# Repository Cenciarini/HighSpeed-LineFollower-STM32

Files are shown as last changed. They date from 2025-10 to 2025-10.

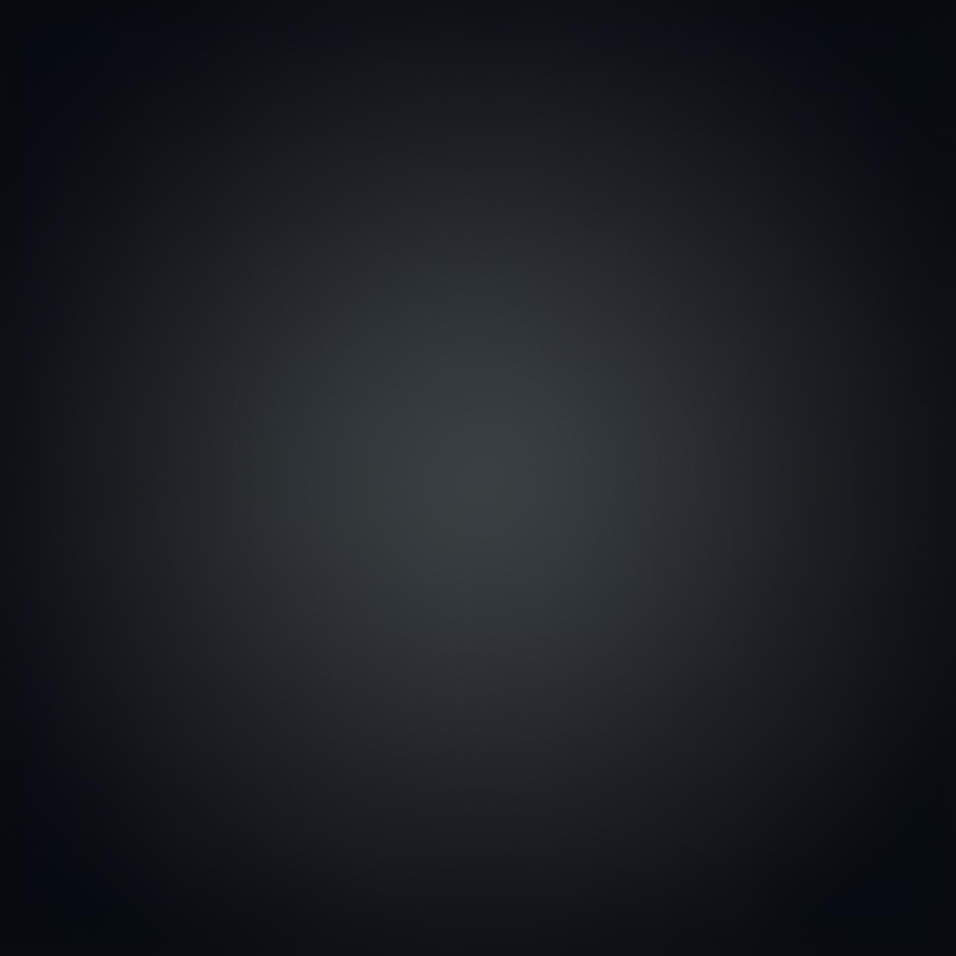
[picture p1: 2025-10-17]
QT_Micro/Imagenes/fondo.png

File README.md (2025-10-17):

# 🚀 High-Speed Line Follower Robot — STM32 Bluepill






---

## 📖 Descripción general

Este proyecto presenta el desarrollo completo de un **robot móvil seguidor de línea de alta velocidad**, basado en un **microcontrolador STM32F103C8T6 (Bluepill)**.  
El sistema fue diseñado para lograr **gran precisión y estabilidad a altas velocidades** mediante el uso de **controladores PID independientes para cada rueda** y una arquitectura modular que integra hardware, firmware, modelado 3D y una interfaz de control desde PC.

El robot combina múltiples disciplinas de ingeniería:  
- ⚙️ **Diseño electrónico y PCB**  
- 💻 **Programación embebida en C**  
- 🧠 **Control en tiempo real (PID)**  
- 🌐 **Comunicación inalámbrica vía ESP32 / UDP**  
- 🖥️ **Interfaz gráfica en C++ con Qt Creator**  
- 🧩 **Diseño mecánico en SolidWorks**

---

## 🧰 Estructura del repositorio

```
📦 RobotLineFollower_STM32
│
├── PCB_Micro/
│   ├── schematics/
│   ├── gerbers/
│   └── README.md
│   📘 Contiene el diseño electrónico completo en KiCAD.
│
├── QT_Micro/
│   ├── mainwindow.cpp
│   ├── resources/
│   └── README.md
│   💻 Interfaz de usuario en Qt Creator (C++) para control remoto y monitoreo.
│
├── SOLID_Micro/
│   ├── ensamblajes/
│   ├── piezas/
│   └── archivos_stl/
│   🧩 Modelos 3D y partes imprimibles diseñadas en SolidWorks.
│
├── ST_Micro/
│   ├── Core/
│   ├── Drivers/
│   ├── Src/
│   └── Inc/
│   ⚙️ Proyecto en STM32CubeIDE con firmware completo para el Bluepill.
│
└── README.md
```

---

## ⚙️ ST_Micro — Firmware embebido

El firmware principal está implementado en **C** dentro de `STM32CubeIDE`, con soporte para múltiples periféricos del microcontrolador.  
Entre sus módulos más relevantes se incluyen:

### 🔧 Periféricos utilizados
- **I2C:** Lectura de sensor **MPU6050** (acelerómetro + giroscopio).  
- **DMA:** Adquisición continua de señales **ADC** para los sensores IR.  
- **PWM:** Control preciso de la velocidad de cada motor DC.  
- **UART:** Comunicación con módulo **ESP01 (WiFi)** para envío de datos vía UDP.  
- **Timers:** Sincronización de tareas y control de tiempo de muestreo.  
- **ADC:** Lectura analógica de los sensores de línea.  

### 🧠 Control PID
El control PID ajusta dinámicamente las velocidades de ambas ruedas para mantener el robot centrado sobre la línea incluso en curvas pronunciadas o a altas velocidades.

El algoritmo se ejecuta en tiempo real y los parámetros **Kp, Ki, Kd** pueden modificarse desde la interfaz gráfica mediante comunicación **UDP**.

### 🧾 Librerías implementadas
- `comunicaciones.c`: Implementa un protocolo propio con chequeo de errores y estructura de tramas (`HEADER`, `NBYTES`, `PAYLOAD`, `CKS`).  
- `ESP01.c`: Gestión completa del módulo WiFi ESP01 con comandos AT y control de estados.  
- `ssd1306.c` y `fonts.c`: Control del display OLED (visualización de estados del robot).  
- `main.c`: Orquesta la lógica principal, incluyendo adquisición de datos, control PID, comunicación, y visualización en pantalla.

---

## 💻 QT_Micro — Interfaz gráfica de control

Desarrollada en **Qt Creator (C++)**, esta interfaz permite:

- Conexión con el robot a través de **UDP (ESP32 o ESP01)**.  
- Ajuste dinámico de parámetros PID (Kp, Ki, Kd) para cada rueda.  
- Visualización en tiempo real de:
  - Estado del robot y sensores IR.
  - Gráficos del recorrido.
  - Datos del MPU6050 (ángulos, aceleraciones).  
- Control remoto del robot (inicio/parada, velocidad base, direcciones, etc.).

---

## ⚡ PCB_Micro — Electrónica y PCB

Diseñada completamente en **KiCAD**, esta placa integra:

- Microcontrolador **STM32F103C8T6** (Bluepill).  
- Etapa de potencia con control PWM para motores DC.  
- Sensores IR analógicos para detección de línea.  
- Reguladores de tensión y protección de alimentación.  
- Conectores para display OLED, ESP01, MPU6050 y ST-Link.  

Incluye:
- Archivos **.sch** (esquemáticos)
- Archivos **.kicad_pcb**
- Archivos **Gerber** listos para fabricación

---

## 🧩 SOLID_Micro — Diseño mecánico

El diseño mecánico del robot fue modelado íntegramente en **SolidWorks**, con foco en minimizar peso y tamaño manteniendo la rigidez estructural.  
Se incluyen:
- Ensambles del chasis y soporte de sensores.  
- Piezas STL listas para impresión 3D.  
- Montaje optimizado del PCB y baterías.

---

## 📡 Comunicación y protocolo

El robot y la interfaz de PC se comunican mediante **UDP**, usando un **protocolo propio de mensajes binarios** desarrollado en C.  
Cada mensaje posee estructura de seguridad y verificación de checksum, garantizando robustez en entornos de alta velocidad.

---

## 🧠 Principales características técnicas

| Componente | Descripción |
|---|---|
| **Microcontrolador** | STM32F103C8T6 (Cortex-M3, 72 MHz) |
| **Sensores** | IR analógicos + MPU6050 (I2C) |
| **Pantalla** | OLED SSD1306 (I2C) |
| **Comunicación** | ESP01 (UART → UDP) / Interfaz Qt |
| **Control** | PID doble canal (rueda izquierda / derecha) |
| **Alimentación** | Batería Li-Po 7.4V con regulación interna |
| **Software principal** | STM32CubeIDE, KiCAD, Qt Creator, SolidWorks |

---

## 🧠 Habilidades demostradas

Este proyecto refleja competencias avanzadas en:

- Diseño y fabricación de **PCBs profesionales** con KiCAD.  
- Programación de **firmware embebido en C para microcontroladores STM32**.  
- Implementación de **controladores PID en tiempo real**.  
- Desarrollo de **protocolos de comunicación personalizados**.  
- Integración de **periféricos complejos (ADC, DMA, I2C, UART, PWM)**.  
- Diseño de **interfaces gráficas multiplataforma (Qt Creator)**.  
- Diseño **mecánico 3D y prototipado rápido (SolidWorks)**.  

---

## 📄 Licencia

Este proyecto está licenciado bajo los términos de la **MIT License**.  
Consulta el archivo [LICENSE](LICENSE) para más información.

---

## 👤 Autor

**Gabriel Cenciarini**  
Ingeniero Mecatrónico
📧 [LinkedIn](https://www.linkedin.com/in/cenciarinigabriel/) | 💻 [GitHub](https://github.com/Cenciarini)

---

> “La integración entre electrónica, software y control no solo construye robots, sino ingenieros capaces de pensar en sistemas completos.”

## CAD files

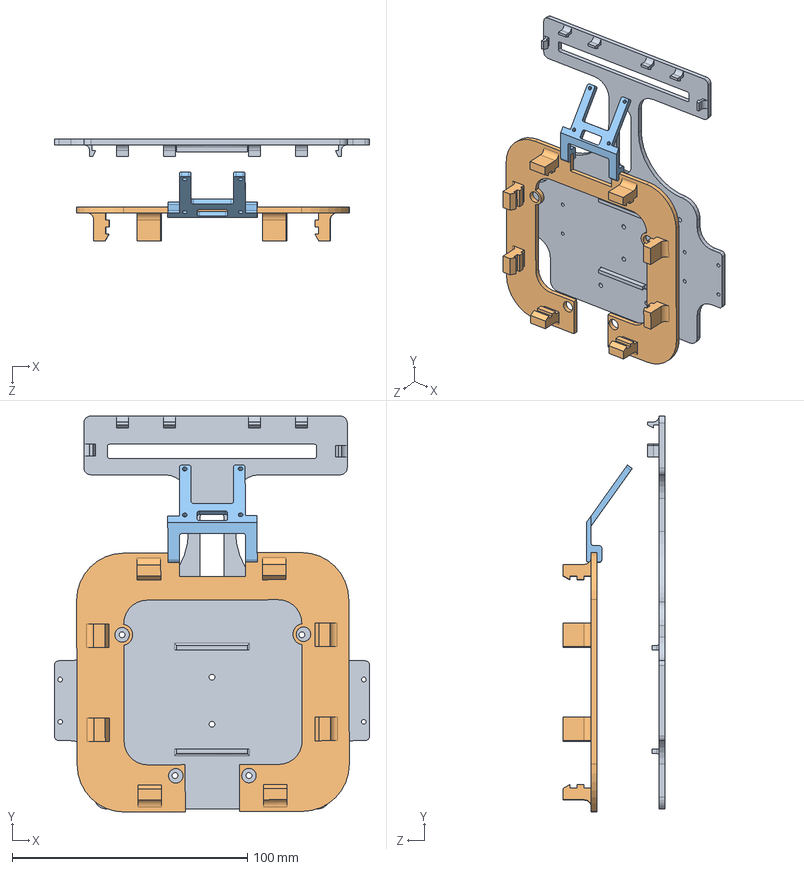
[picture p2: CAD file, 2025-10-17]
SOLID_Micro/Ensamblaje1.SLDASM
134.0 x 168.3 x 43.4 mm
Base
PiezaSuperior
Pantalla

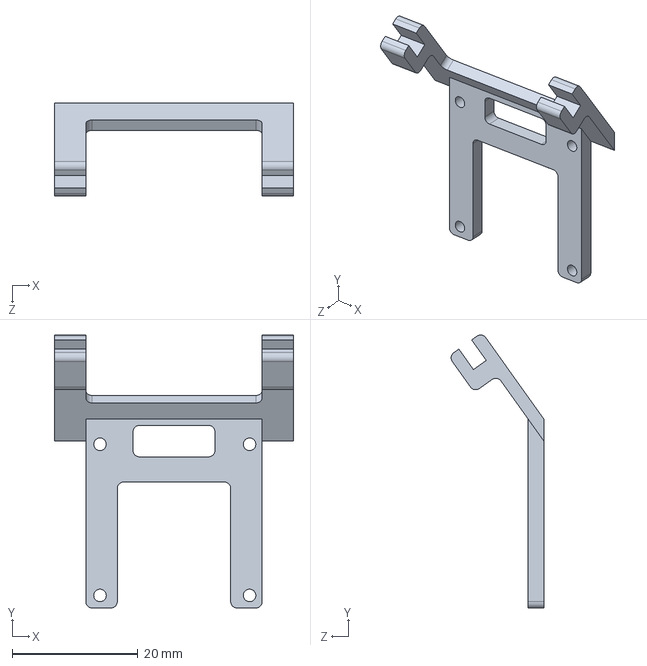
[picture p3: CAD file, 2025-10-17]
SOLID_Micro/Pantalla.SLDPRT
38.0 x 43.4 x 14.7 mm

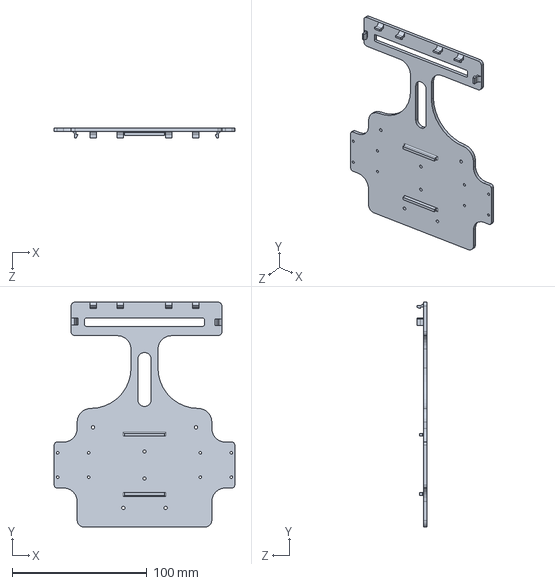
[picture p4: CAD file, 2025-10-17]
SOLID_Micro/Base.SLDPRT
134.0 x 167.0 x 7.50 mm

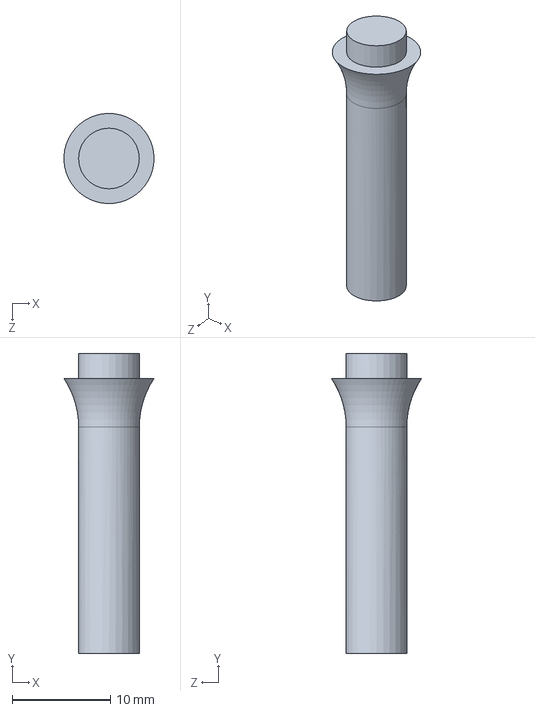
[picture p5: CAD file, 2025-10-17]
SOLID_Micro/Columna.SLDPRT
9.19 x 30.6 x 9.19 mm

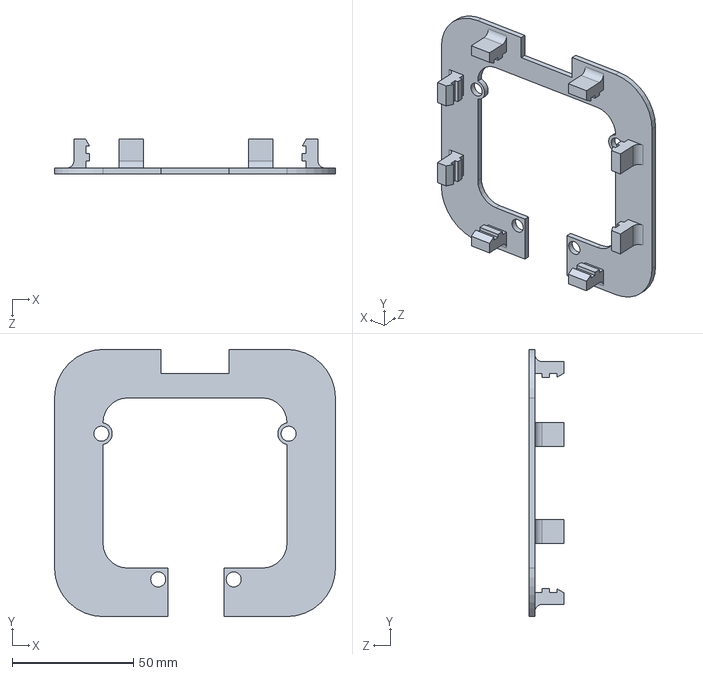
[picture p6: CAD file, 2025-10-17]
SOLID_Micro/PiezaSuperior.SLDPRT
115.7 x 110.0 x 14.5 mm

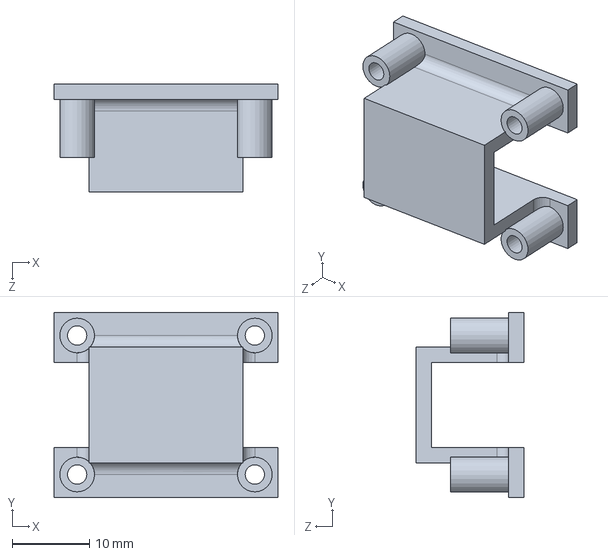
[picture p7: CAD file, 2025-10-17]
SOLID_Micro/SoporteMotor.SLDPRT
29.0 x 24.0 x 14.0 mm

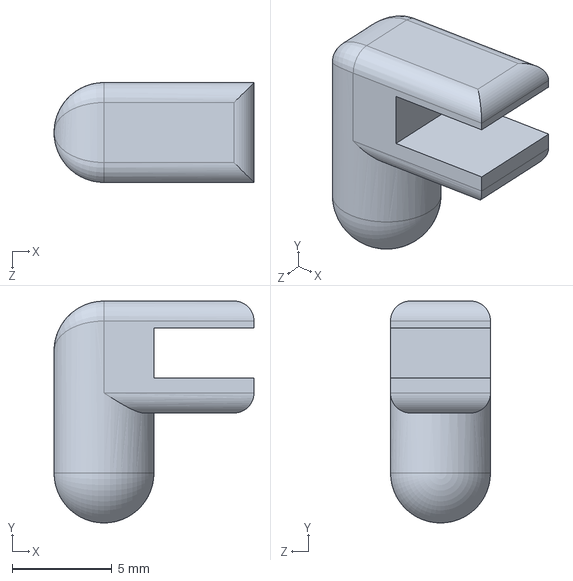
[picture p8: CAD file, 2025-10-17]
SOLID_Micro/Apoyo.SLDPRT
10.0 x 11.1 x 5.00 mm

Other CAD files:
SOLID_Micro/STLs/Apoyo.STL
SOLID_Micro/STLs/Base.STL
SOLID_Micro/STLs/Columna.STL
SOLID_Micro/STLs/Pantalla.STL
SOLID_Micro/STLs/PiezaSuperior.STL
SOLID_Micro/STLs/SoporteMotor.STL

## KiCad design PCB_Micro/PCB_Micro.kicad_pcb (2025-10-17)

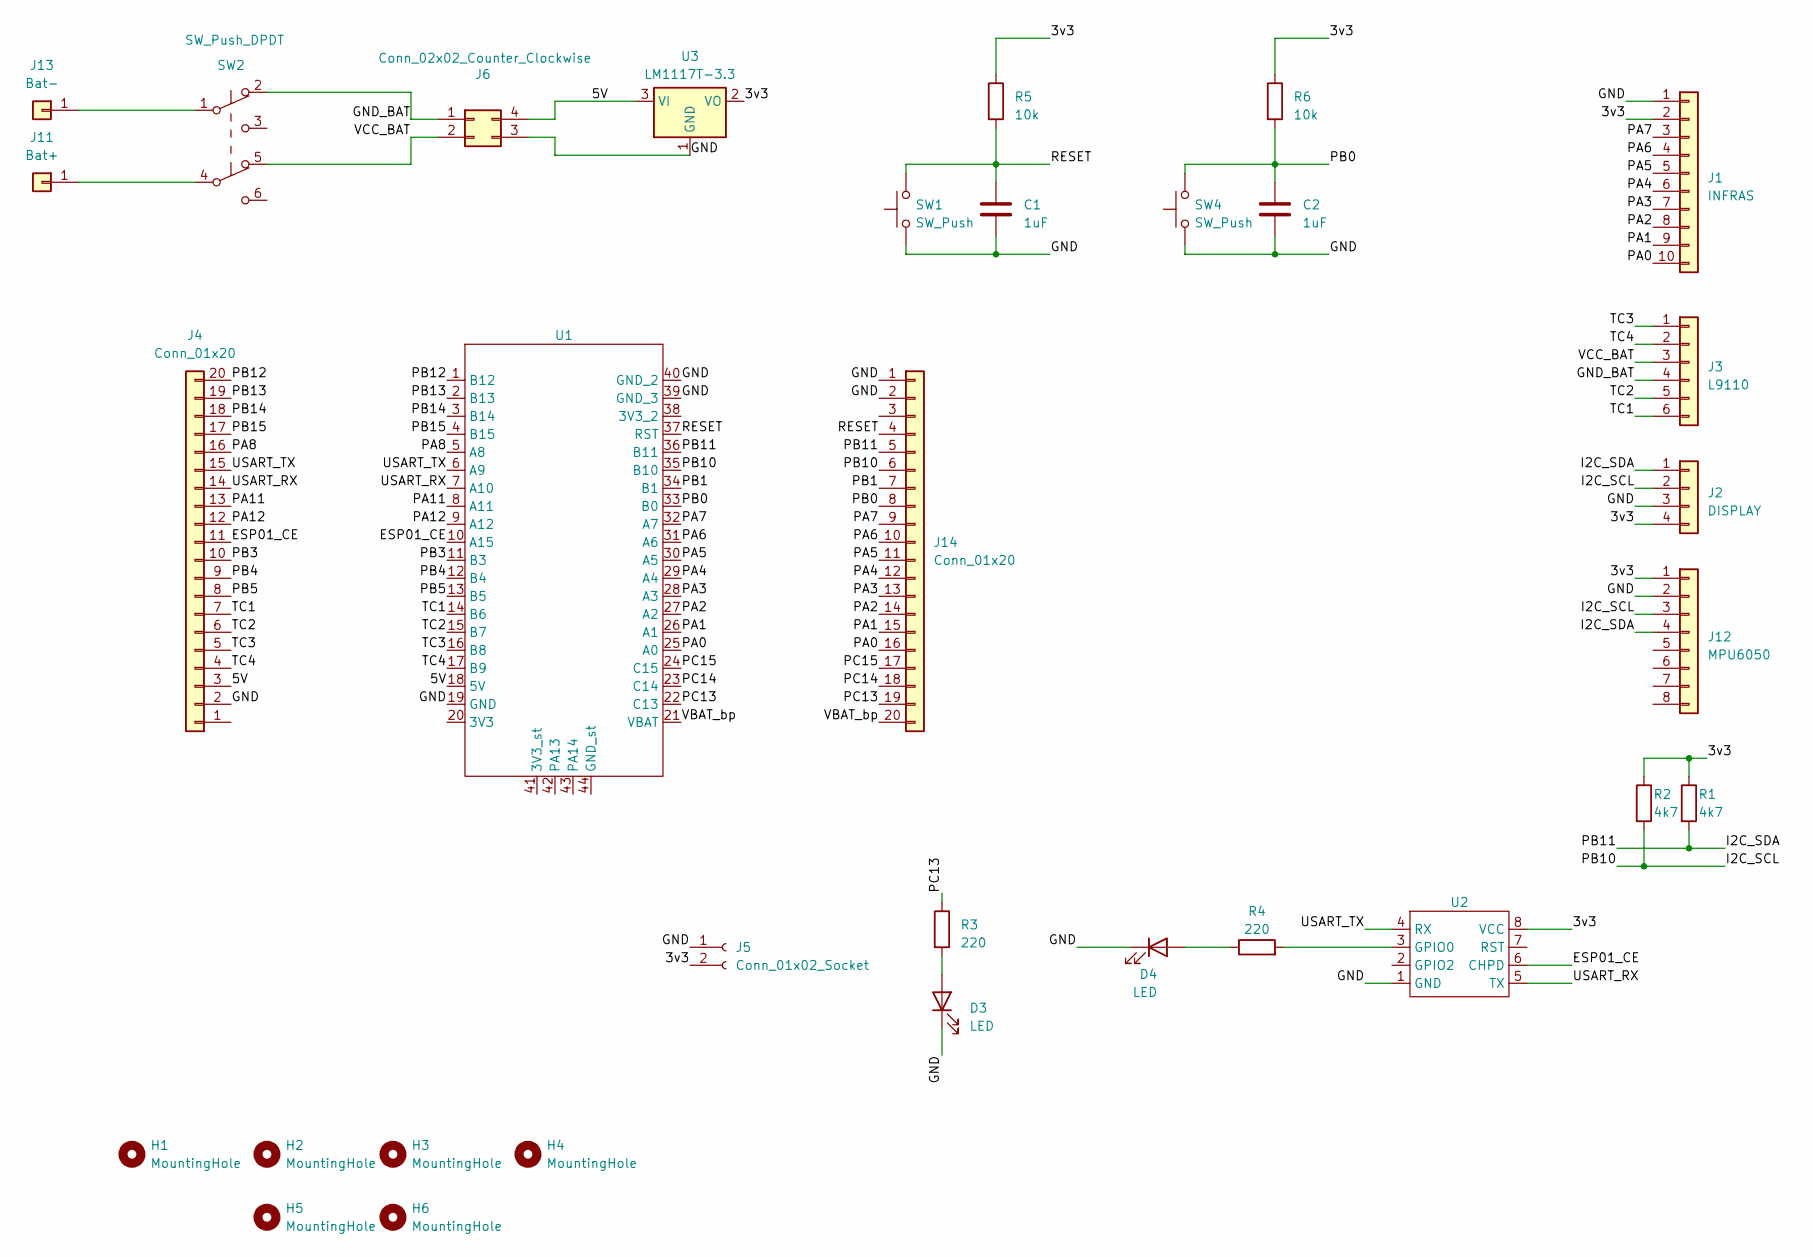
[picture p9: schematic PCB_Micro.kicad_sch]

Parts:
C1, C2: 1uF; C_Disc_D3.8mm_W2.6mm_P2.50mm
D3, D4: LED; LED_D3.0mm
H1, H2, H3, H4, H5, H6: MountingHole; MountingHole_3.2mm_M3
J1: INFRAS; PinHeader_1x10_P2.54mm_Horizontal
J2: DISPLAY; PinSocket_1x04_P2.54mm_Vertical
J3: L9110; PinSocket_1x06_P2.54mm_Vertical
J4, J14: Conn_01x20; PinSocket_1x20_P2.54mm_Vertical
J5: Conn_01x02_Socket; PinSocket_1x02_P2.54mm_Vertical
J6: Conn_02x02_Counter_Clockwise; MINI360Module
J11: Bat+; PinSocket_1x01_P2.54mm_Vertical
J12: MPU6050; PinSocket_1x08_P2.54mm_Vertical
J13: Bat-; PinSocket_1x01_P2.54mm_Vertical
R1, R2: 4k7; R_Axial_DIN0207_L6.3mm_D2.5mm_P10.16mm_Horizontal
R3, R4: 220; R_Axial_DIN0207_L6.3mm_D2.5mm_P10.16mm_Horizontal
R5, R6: 10k; R_Axial_DIN0207_L6.3mm_D2.5mm_P10.16mm_Horizontal
SW1, SW4: SW_Push; SW_PUSH_6mm_H4.3mm
SW2: SW_Push_DPDT; SW_Push_2P2T_Toggle_CK_PVA2xxH1xxxxxxV2
U1: STM32BluePill
U2: XCVR_ESP8266-01_ESP-01
U3: LM1117T-3.3; TO-220-3_Vertical

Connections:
/3v3: J1.2, J2.4, J5.2, J12.1, R1.1, R2.1, R5.1, R6.1, U2.8 (VCC), U3.2 (VO)
/5V: J4.3, J6.4, U1.18 (5V), U3.3 (VI)
/ESP01_CE: J4.11, U1.10 (A15), U2.6 (CHPD)
/GND: C1.2, C2.2, D3.1 (K), D4.1 (K), J1.1, J2.3, J4.2, J5.1, J6.3, J12.2, J14.1, J14.2, SW1.1, SW4.1, U1.19 (GND), U1.39 (GND_3), U1.40 (GND_2), U2.1 (GND), U3.1 (GND)
/GND_BAT: J3.4, J6.1, SW2.2 (A)
/I2C_SCL: J2.2, J12.3, J14.6, R2.2, U1.35 (B10)
/I2C_SDA: J2.1, J12.4, J14.5, R1.2, U1.36 (B11)
/PA0: J1.10, J14.16, U1.25 (A0)
/PA1: J1.9, J14.15, U1.26 (A1)
/PA2: J1.8, J14.14, U1.27 (A2)
/PA3: J1.7, J14.13, U1.28 (A3)
/PA4: J1.6, J14.12, U1.29 (A4)
/PA5: J1.5, J14.11, U1.30 (A5)
/PA6: J1.4, J14.10, U1.31 (A6)
/PA7: J1.3, J14.9, U1.32 (A7)
/PA8: J4.16, U1.5 (A8)
/PA11: J4.13, U1.8 (A11)
/PA12: J4.12, U1.9 (A12)
/PB0: C2.1, J14.8, R6.2, SW4.2, U1.33 (B0)
/PB1: J14.7, U1.34 (B1)
/PB3: J4.10, U1.11 (B3)
/PB4: J4.9, U1.12 (B4)
/PB5: J4.8, U1.13 (B5)
/PB12: J4.20, U1.1 (B12)
/PB13: J4.19, U1.2 (B13)
/PB14: J4.18, U1.3 (B14)
/PB15: J4.17, U1.4 (B15)
/PC13: J14.19, R3.1, U1.22 (C13)
/PC14: J14.18, U1.23 (C14)
/PC15: J14.17, U1.24 (C15)
/RESET: C1.1, J14.4, R5.2, SW1.2, U1.37 (RST)
/TC1: J3.6, J4.7, U1.14 (B6)
/TC2: J3.5, J4.6, U1.15 (B7)
/TC3: J3.1, J4.5, U1.16 (B8)
/TC4: J3.2, J4.4, U1.17 (B9)
/USART_RX: J4.14, U1.7 (A10), U2.5 (TX)
/USART_TX: J4.15, U1.6 (A9), U2.4 (RX)
/VBAT_bp: J14.20, U1.21 (VBAT)
/VCC_BAT: J3.3, J6.2, SW2.5 (A)
unnamed: D3.2 (A), R3.2
unnamed: D4.2 (A), R4.1
unnamed: J11.1, SW2.4 (B)
unnamed: J13.1, SW2.1 (B)
unnamed: R4.2, U2.3 (GPIO0)

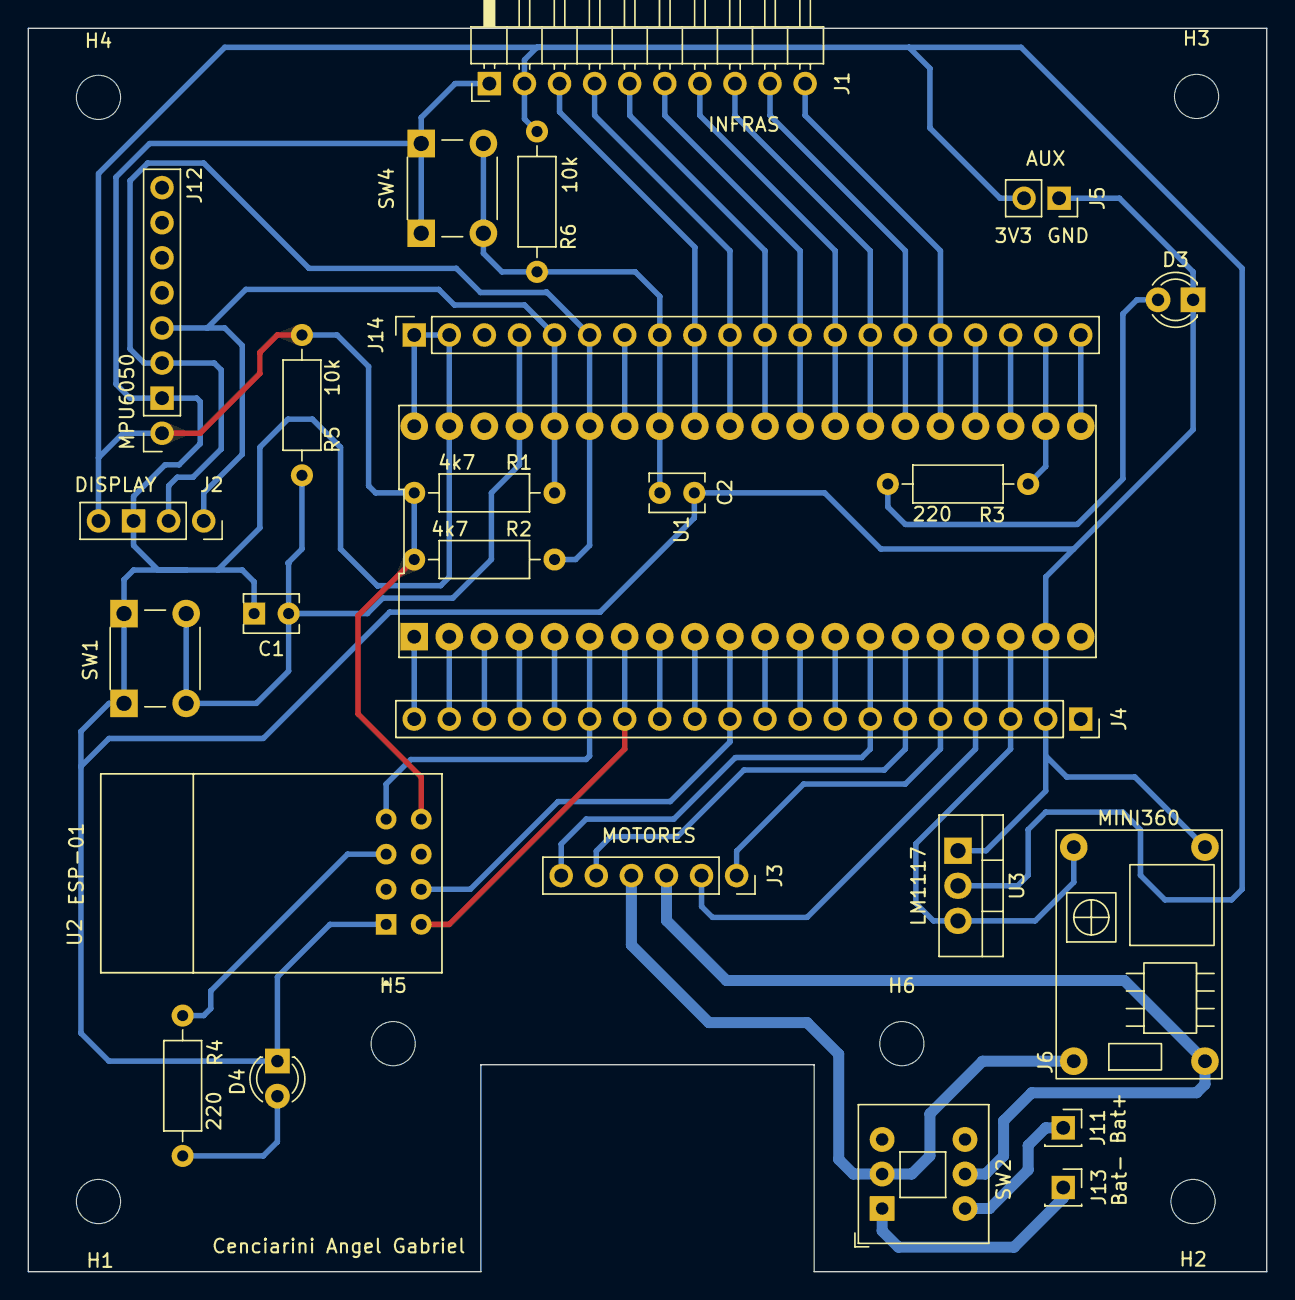
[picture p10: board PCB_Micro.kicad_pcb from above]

Board: 2 copper layers, 89.7 x 90.0 mm, 32 parts (0 on the bottom side), 44 nets.

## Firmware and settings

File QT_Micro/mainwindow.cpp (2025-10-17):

#include "mainwindow.h"
#include "ui_mainwindow.h"
#include <QtNetwork/QUdpSocket>
#include <QElapsedTimer>
#include <QPixmap>
#include <qdebug.h>

#define PI 3.14159162
#define H 54.0
#define Alpha 0.97738

MainWindow::MainWindow(QWidget *parent)
    : QMainWindow(parent)
    , ui(new Ui::MainWindow)
{
    ui->setupUi(this);

    // Initialize the track visualization widget
    Qpista1 = new qpista(1348,561,ui->QPista);

    // Initialize UDP sockets for communication
    mSocket_send = new QUdpSocket(this);
    mSocket_recive = new QUdpSocket(this);

    // Bind receiving socket to local IP and port for listening
    mSocket_recive->bind(QHostAddress("192.168.2.114"), 30001, QUdpSocket::ShareAddress);

    // Connect signal for incoming data to read handler
    connect(mSocket_recive, &QUdpSocket::readyRead, this, &MainWindow::readDatagrams);
}

MainWindow::~MainWindow()
{
    // Clean up dynamically allocated memory
    delete Qpista1;
    delete ui;
}

//-------------------------------------------------------------------------------------------------
// Resize event handler: updates the track widget size and UI labels when the main window resizes.
//-------------------------------------------------------------------------------------------------
void MainWindow::resizeEvent(QResizeEvent */*event*/)
{
    Qpista1->resize(ui->QPista->size());
    ui->label_5->setText(QString().number(ui->QPista->width()));
    ui->label_6->setText(QString().number(ui->QPista->height()));
}

//-------------------------------------------------------------------------------------------------
// Paint event: ensures the track is resized only once during initial rendering.
//-------------------------------------------------------------------------------------------------
void MainWindow::paintEvent(QPaintEvent */*event*/)
{
    static bool first = false;

    if(!first){
        Qpista1->resize(ui->QPista->size());
        first = true;
    }
}

//-------------------------------------------------------------------------------------------------
// Sends the currently selected datagram command over UDP when the push button is clicked.
//-------------------------------------------------------------------------------------------------
void MainWindow::on_pushButton_clicked()
{
    datagramaWrite.resize(seleccion.size());
    datagramaWrite = seleccion;

    if(commandSend == 172){
        firstRead = 1;
    }
    if(commandSend == 171){
        raceStart = !raceStart;
    }

    qDebug() << commandSend;

    // Transmit datagram to target device (local or lab)
    mSocket_send->writeDatagram(datagramaWrite, QHostAddress("192.168.2.115"), 30010);  // Home
    //mSocket_send->writeDatagram(datagramaWrite, QHostAddress("192.168.2.108"), 30001); // Lab prototype
}

//-------------------------------------------------------------------------------------------------
// Updates the datagram structure according to the selected command in the combo box.
//-------------------------------------------------------------------------------------------------
void MainWindow::on_comboBox_currentIndexChanged(int index)
{
    seleccion.resize(9);

    switch (index) {
    case 0:
        break;
    case 1:
        // ALIVE command
        seleccion[0] = 'U';
        seleccion[1] = 'N';
        seleccion[2] = 'E';
        seleccion[3] = 'R';
        seleccion[4] = 0x02;
        seleccion[5] = 0x3A;
        seleccion[6] = 0xF0;
        seleccion[7] = 0xC4;
        seleccion[8] = '\0';
        break;
    case 2:
        // Accelerometer/Gyroscope data request
        seleccion[0] = 'U';
        seleccion[1] = 'N';
        seleccion[2] = 'E';
        seleccion[3] = 'R';
        seleccion[4] = 0x02;
        seleccion[5] = 0x3A;
        seleccion[6] = 0xAC;
        seleccion[7] = 0x98;
        seleccion[8] = '\0';
        break;
    case 3:
        // Command for another operation
        seleccion[0] = 'U';
        seleccion[1] = 'N';
        seleccion[2] = 'E';
        seleccion[3] = 'R';
        seleccion[4] = 0x02;
        seleccion[5] = 0x3A;
        seleccion[6] = 0xAB;
        seleccion[7] = 0x9F;
        seleccion[8] = '\0';
        break;
    case 4:
        // Alternative system command
        seleccion[0] = 'U';
        seleccion[1] = 'N';
        seleccion[2] = 'E';
        seleccion[3] = 'R';
        seleccion[4] = 0x02;
        seleccion[5] = 0x3A;
        seleccion[6] = 0xA5;
        seleccion[7] = 0x91;
        seleccion[8] = '\0';
        break;
    default:
        break;
    }

    commandSend = seleccion[6];
}

//-------------------------------------------------------------------------------------------------
// Reads available UDP datagrams and triggers the decoding routine.
//-------------------------------------------------------------------------------------------------
void MainWindow::readDatagrams()
{
    if(mSocket_recive->hasPendingDatagrams()) {
        datagramaRead.resize(int(mSocket_recive->pendingDatagramSize()));
        mSocket_recive->readDatagram(datagramaRead.data(),datagramaRead.size());
    }
    decodeDatagram();
}

//-------------------------------------------------------------------------------------------------
// Decodes incoming datagrams using a finite state machine to verify header, payload, and checksum.
//-------------------------------------------------------------------------------------------------
void MainWindow::decodeDatagram()
{
    uint8_t index = 0, indexPayload = 0;

    while (index != datagramaRead.size()) {
        switch (stateDecode)
        {
        case 0:
            // Expect header byte 'U'
            if (datagramaRead[index++] == 'U') {
                stateDecode = 1;
                cksRx = 0;
            }else{
                stateDecode = 0;
                command = ERROR;
                return;
            }
            break;
        case 1:
            // Expect 'N'
            if (datagramaRead[index++] == 'N') {
                stateDecode = 2;
            }else{
                stateDecode = 0;
                command = ERROR;
                return;
            }
            break;
        case 2:
            // Expect 'E'
            if (datagramaRead[index++] == 'E'){
                stateDecode = 3;
            }else{
                stateDecode = 0;
                command = ERROR;
                return;
            }
            break;
        case 3:
            // Expect 'R'
            if (datagramaRead[index++] == 'R'){
                stateDecode = 4;
            }else{
                stateDecode = 0;
                command = ERROR;
                return;
            }
            break;
        case 4:
            // Payload size
            nBytes = datagramaRead[index++];
            stateDecode = 5;
            break;
        case 5:
            // Expect ':' separator and compute checksum seed
            if (datagramaRead[index++] == ':'){
                stateDecode = 6;
                cksRx = 'U' ^ 'N' ^ 'E' ^ 'R' ^ nBytes ^ ':';
                indexPayload = 0;
            }else{
                stateDecode = 0;
                command = ERROR;
                return;
            }
            break;
        case 6:
            // Read payload and update checksum
            if(nBytes > 1){
                buff[indexPayload++] = datagramaRead[index];
                cksRx ^= datagramaRead[index++];
            }
            nBytes--;
            // Validate checksum once payload is complete
            if(nBytes == 0){
                stateDecode = 0;
                uint8_t cksRxAux = datagramaRead[index];
                if(cksRx == cksRxAux){
                    analisisData();
                }
            }
            break;
        default:
            break;
        }
    }
}

//-------------------------------------------------------------------------------------------------
// Processes valid decoded data depending on the command type and updates the GUI accordingly.
//-------------------------------------------------------------------------------------------------
void MainWindow::analisisData()
{
    switch (buff[0]) {
    case 0xF0:
        ui->label_7->setText("Estoy vivo");
        break;

    case 0xAC:  {
        // Parse IMU data (accelerometer and gyroscope)
        accelX = (buff[1] << 8) | buff[2];
        accelY = (buff[3] << 8) | buff[4];
        gyroZ = (buff[5] << 8) | buff[6];

        // Initialize variables
        gZ = 0.0;
        aX = 0.0;
        aY = 0.0;
        theta = 0.0;

        // Convert raw data to physical units
        gZ = ((float)gyroZ / 131.0);
        aX = ((float)accelX / 16384.0) * 9810.0;
        aY = ((float)accelY / 16384.0) * 9810.0;

        aX *= 2;
        aY *= 2;

        // Offset calibration at first reading
        if(firstRead == 1){
            timer.start();
            aYOffset = aY;
            aXOffset = aX;
            gZOffset = gZ;
            firstRead = 0;
        }else{
            // Apply offset compensation
            aX -= aXOffset;
            aY -= aYOffset;
            gZ -= gZOffset;

            // Deadband filtering for noise reduction
            if(aY > -50.0 && aY < 50.0) aY = 0.0;
            if(aX > -50.0 && aX < 50.0) aX = 0.0;

            dT = timer.elapsed() / 1000.0;
            timer.restart();

            // Integrate angular rate to compute orientation
            if(gZ > -1.0 && gZ < 1.0){
                gZ = 0.0;
            }else{
                gZ = (gZ * dT)/ 3.1415916;
                gT += gZ;
            }

            // Keep orientation within 0–2π range
            if(gT > (2*PI)) gT -= (2 * PI);
            if(gT < 0.0) gT = (2 * PI) - gT;

            QString qvalor;
            ui->label->setText(qvalor.number(aX));
            ui->label_2->setText(qvalor.number(aY));
            ui->label_3->setText(qvalor.number(gZ));

            // Compute displacement based on acceleration and time
            aT = sqrt((aX * aX) + (aY * aY));
            sT = 0.5 * aT * dT * dT;

            sXo = sT * sin(gT);
            sYo = sT * cos(gT);

            sXf += sXo;
            sYf += sYo;

            ui->label_5->setText(qvalor.number(gT));
            ui->label_6->setText(qvalor.number(gyroDerCount));

            // Draw circuit path if enabled and race started
            if(circuitDraw == 1 && raceStart == 1){
                updateCircuitDraw();
            }
        }
        break;
    }

    case 0xAA:  {
        // Debug or status message
        char valor = buff[1];
        int ivalor = (int)valor;
        QString qvalor;
        ui->label_7->setText(qvalor.number(ivalor));
        break;
    }

    case 0xA7: {
        // Parse ADC and PWM data for IR sensors or motors
        adc_value = buff[1];
        pwmIzq = (buff[2] << 8) | buff[3];
        pwmDer = (buff[4] << 8) | buff[5];
        rateError = (int)(buff[6] << 8) | buff[7];
        QString qvalor;
        ui->label_5->setText(qvalor.number(pwmIzq));
        ui->label_6->setText(qvalor.number(pwmDer));
        ui->label_7->setText(qvalor.number(rateError));
        updateADCread();
    }
    default:
        break;
    }
}

//-------------------------------------------------------------------------------------------------
// Visualizes ADC sensor data as a graphical bar indicator on the track canvas.
//-------------------------------------------------------------------------------------------------
void MainWindow::updateADCread()
{
    QPen pen;
    QPainter paint(Qpista1->getCanvas());
    QPoint point, point_adc;
    QPoint puntoIzq, puntoDer;

    puntoIzq.setX(404);
    puntoIzq.setY(200);
    puntoDer.setX(944);
    puntoDer.setY(200);

    Qpista1->getCanvas()->fill(Qt::white);
    pen.setWidth(3);
    pen.setColor(Qt::darkBlue);
    paint.setPen(pen);
    paint.drawLine(puntoIzq,puntoDer);

    adc_value += 36;
    adc_value = adc_value/4;

    point.setX(944 - adc_value * 30);
    point.setY(170);
    point_adc.setX(944 - adc_value * 30);
    point_adc.setY(230);

    pen.setWidth(20);
    pen.setColor(Qt::darkGray);
    paint.setPen(pen);
    paint.drawLine(point,point_adc);

    Qpista1->update();
}

//-------------------------------------------------------------------------------------------------
// Draws the current trajectory of the system on the virtual track canvas.
//-------------------------------------------------------------------------------------------------
void MainWindow::updateCircuitDraw()
{
    QPen pen;
    QPainter paint(Qpista1->getCanvas());

    if(firstUpdate == 1){
        pointAnt.setX(700);
        pointAnt.setY(300);
        firstUpdate = 0;
    }

    pActX = sXf + 700;
    pActY = sYf + 300;

    pointAct.setX(pActX);
    pointAct.setY(pActY);

    pAntX = pActX;
    pAntY = pActY;

    pen.setWidth(2);
    pen.setColor(Qt::darkBlue);
    paint.setPen(pen);
    paint.drawLine(pointAnt,pointAct);
    Qpista1->update();

    pointAnt.setX(pAntX);
    pointAnt.setY(pActY);
}

//-------------------------------------------------------------------------------------------------
// Sends PID configuration parameters to the remote system via UDP.
//-------------------------------------------------------------------------------------------------
void MainWindow::on_pushButton_2_clicked()
{
    PIDdatagram.resize(16);

    PIDdatagram[0] = 'U';
    PIDdatagram[1] = 'N';
    PIDdatagram[2] = 'E';
    PIDdatagram[3] = 'R';
    PIDdatagram[4] = 0x09;
    PIDdatagram[5] = 0x3A;
    PIDdatagram[6] = 0xA6;
    PIDdatagram[7] = (char)ui->KpIzq->value();
    PIDdatagram[8] = (char)(ui->KdIzq->value() >> 8);
    PIDdatagram[9] = (char)ui->KdIzq->value();
    PIDdatagram[10] = (char)ui->KpDer->value();
    PIDdatagram[11] = (char)(ui->KdDer->value() >> 8);
    PIDdatagram[12] = (char)ui->KdDer->value();
    PIDdatagram[13] = (char)ui->VelPorc->value();

    // Compute XOR-based checksum for datagram integrity
    PIDdatagram[14] = 'U' ^ 'N' ^ 'E' ^ 'R' ^ 0x09 ^ ':' ^ 0xA6 ^ PIDdatagram[7] ^ PIDdatagram[8]  ^ PIDdatagram[9] ^ PIDdatagram[10] ^ PIDdatagram[11] ^ PIDdatagram[12] ^ PIDdatagram[13];
    PIDdatagram[15] = '\0';

    datagramaWrite.resize(PIDdatagram.size());
    datagramaWrite = PIDdatagram;

    //mSocket_send->writeDatagram(datagramaWrite, QHostAddress("192.168.2.108"), 30001); // Lab prototype
    mSocket_send->writeDatagram(datagramaWrite, QHostAddress("192.168.2.115"), 30010);  // Home
}

//-------------------------------------------------------------------------------------------------
// Handles IR sensor visualization toggle and sends corresponding command to the remote system.
//-------------------------------------------------------------------------------------------------
void MainWindow::on_checkBox_stateChanged(int arg1)
{
    QPen pen;
    QPainter paint(Qpista1->getCanvas());
    QPoint puntoIzq, puntoDer;

    puntoIzq.setX(404);
    puntoIzq.setY(200);
    puntoDer.setX(944);
    puntoDer.setY(200);

    if(arg1){
        Qpista1->getCanvas()->fill(Qt::white);
        pen.setWidth(3);
        pen.setColor(Qt::darkBlue);
        paint.setPen(pen);
        paint.drawLine(puntoIzq,puntoDer);
    }else{
        Qpista1->getCanvas()->fill(Qt::white);
    }
    Qpista1->update();

    // Build and send IR command datagram
    IRdatagram.resize(9);
    IRdatagram[0] = 'U';
    IRdatagram[1] = 'N';
    IRdatagram[2] = 'E';
    IRdatagram[3] = 'R';
    IRdatagram[4] = 0x02;
    IRdatagram[5] = 0x3A;
    IRdatagram[6] = 0xA7;
    IRdatagram[7] = 'U' ^ 'N' ^ 'E' ^ 'R' ^ 0x02 ^ ':' ^ 0xA7;
    IRdatagram[8] = '\0';

    datagramaWrite.resize(IRdatagram.size());
    datagramaWrite = IRdatagram;

    //mSocket_send->writeDatagram(datagramaWrite, QHostAddress("192.168.2.108"), 30001); // Lab prototype
    mSocket_send->writeDatagram(datagramaWrite, QHostAddress("192.168.2.115"), 30010);  // Home
}

//-------------------------------------------------------------------------------------------------
// Handles circuit drawing checkbox: toggles visualization of trajectory plotting.
//-------------------------------------------------------------------------------------------------
void MainWindow::on_checkBox_2_stateChanged(int arg1)
{
    if(arg1){
        Qpista1->getCanvas()->fill(Qt::white);
        circuitDraw = 1;
        firstUpdate = 1;
    }else{
        Qpista1->getCanvas()->fill(Qt::white);
        circuitDraw = 0;
    }
    Qpista1->update();
}

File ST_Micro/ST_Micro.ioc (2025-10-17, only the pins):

Mcu.UserName=STM32F103C8Tx
PA0-WKUP.Signal=ADCx_IN0
PA1.Signal=ADCx_IN1
PA10.Signal=USART1_RX
PA11.Signal=USB_DM
PA12.Signal=USB_DP
PA13.Signal=SYS_JTMS-SWDIO
PA14.Signal=SYS_JTCK-SWCLK
PA2.Signal=ADCx_IN2
PA3.Signal=ADCx_IN3
PA4.Signal=ADCx_IN4
PA5.Signal=ADCx_IN5
PA6.Signal=ADCx_IN6
PA8.GPIO_Label=ChipEnable
PA8.Signal=GPIO_Output
PA9.Signal=USART1_TX
PB10.Signal=I2C2_SCL
PB11.Signal=I2C2_SDA
PB6.Signal=S_TIM4_CH1
PB7.Signal=S_TIM4_CH2
PB8.Signal=S_TIM4_CH3
PB9.Signal=S_TIM4_CH4
PC13-TAMPER-RTC.GPIO_Label=LED[BUILTIN]
PC13-TAMPER-RTC.Signal=GPIO_Output
PC14-OSC32_IN.Signal=RCC_OSC32_IN
PC15-OSC32_OUT.Signal=RCC_OSC32_OUT
PD0-OSC_IN.Signal=RCC_OSC_IN
PD1-OSC_OUT.Signal=RCC_OSC_OUT

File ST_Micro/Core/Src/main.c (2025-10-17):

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
/* Includes ------------------------------------------------------------------*/
#include "main.h"
#include "usb_device.h"

/* USER CODE BEGIN Includes */
#include <string.h>
#include <stddef.h>
#include "stdint.h"
#include "usbd_cdc_if.h"
#include "comunicaciones.h"
#include "ESP01.h"
#include "stm32f1xx_hal.h"
#include "ssd1306.h"
#include "fonts.h"
/* USER CODE END Includes */

/* USER CODE BEGIN PTD */

typedef enum{
	ALIVE=0xF0,      // Identificador para mensaje de "vivo"
	DATA=0xF1,       // Identificador para transmisión de datos
	DEBUGGER=0xE3,   // Identificador para mensajes de depuración
	AT_TRANSMIT=0xA0,// Identificador para transmisión AT
	AT_CONFIG=0xA1,  // Identificador para configuración AT
	MPU_READ = 0xAC, // Identificador para lectura del sensor MPU
	IR_READ = 0xAB,  // Identificador para lectura de sensores IR
	MOTOR = 0XA5,    // Identificador para control de motores
	PID_CONFIG = 0xA6,// Identificador para configuración PID
	ADC_VALUES = 0XA7,// Identificador para graficar valores ADC
	OTHERS           // Identificador para otros comandos
}_eID;

// Definición de una unión para almacenar banderas de estado
static union{
	struct{
		uint8_t tranparentDebug: 1; // Bandera para modo de depuración transparente
		uint8_t at_transmit: 1;     // Bandera para transmisión AT
		uint8_t comillas: 1;        // Bandera para manejo de comillas en configuración AT
		uint8_t mpu_read: 1;        // Bandera para indicar lectura del sensor MPU
		uint8_t mpu_read_ok: 1;     // Bandera para indicar que la lectura del MPU fue exitosa
		uint8_t ir_read: 1;         // Bandera para indicar lectura de sensores IR
		uint8_t adc_dma_start: 1;   // Bandera para indicar inicio de DMA en ADC
		uint8_t motor_prueba: 1;    // Bandera para prueba de motores
	}bit;
	uint8_t byte;  // Variable de 8 bits para acceder a todas las banderas como un solo byte
}flags;

typedef struct{
	uint8_t bufferRx[256];
	uint8_t bufferTx[256];
	uint8_t bufferPx[256];
	uint8_t Rxir;
	uint8_t Rxiw;
	uint8_t Txir;
	uint8_t Txiw;
	uint8_t Pxir;
	uint8_t Pxiw;
}bufferST;

// Variables para configuración y almacenamiento de datos

SSD1306_COLOR_t color; // Color de la pantalla OLED
//_sESP01_CONFIG myESP01_Config; // Configuración del módulo ESP01
_eESP01STATUS currentESP01states;
bufferST bufferESP01;

/* USER CODE END PTD */

/* USER CODE BEGIN PD */
#define MPU6050_ADDRESS 0xD0 // Dirección I2C del sensor MPU6050
/* USER CODE END PD */

ADC_HandleTypeDef hadc1;
DMA_HandleTypeDef hdma_adc1;

I2C_HandleTypeDef hi2c2;

TIM_HandleTypeDef htim2;
TIM_HandleTypeDef htim3;
TIM_HandleTypeDef htim4;

UART_HandleTypeDef huart1;

/* USER CODE BEGIN PV */

// Variables de uso general
uint8_t tempRxUART[2];
//char dataRXESP01; // Variable para almacenar datos recibidos por UART
uint32_t elapsedHeartBeat = 0, elapsedESP01Receive = 0, elapsedMPU = 0, elapsedMPU_tx = 0, elapseIR = 0, elapsedADC_draw = 0;
uint32_t elapsedESP01TimeOut = 0;
int16_t pwmIzq = 0, pwmDer = 0, pwmIzqInv = 0, pwmDerInv = 0, pwmBase = 999; // Variables de control de PWM
int error = 0, lastError = 0;
int cumError = 0, rateError = 0, correccionDer = 0, correccionIzq = 0; // Variables para control PID
uint8_t KpIzq = 0, KpDer = 0,  Vel = 100; // Coeficientes PID
uint16_t KdIzq = 0, KdDer = 0;
uint8_t raceStart = 0, adcDraw = 0; // Banderas de control

// Buffers para almacenamiento y transmisión de datos
char bufPayloadRx[32]; // Buffer para recepción de datos USB
char bufPayloadTx[32]; // Buffer para transmisión de datos USB
char payloadBck[256];  // Buffer de respaldo para datos USB
char bufDebug[32];      // Buffer para mensajes de depuración
char ipBuf[16];           // Almacenamiento de la dirección IP del ESP01
char *ip;
uint8_t TxLen = 0;

// Variables para lectura del sensor MPU6050
uint8_t MPU_rx[4], accelCount = 0;
int16_t accelXProm = 0, accelYProm = 0, gyroZProm = 0, gyroYProm = 0, gyroZAux[20], gyroYAux[20], accelXAux[20], accelYAux[20];

// Variables para manejo de ADC con DMA
uint32_t adc_dma_value[7], dma_result[7][20], ir_prom_value[7]; // Almacenamiento de valores ADC
uint8_t adc_dma_count = 0;
int8_t line_pos;

// Variables para la detección de la linea
uint8_t max_value_ir = 0;  // Índice del sensor IR con el valor máximo
uint8_t last_ir = 0;
uint32_t max_value = 0;    // Valor máximo encontrado en ir_prom_value

/* USER CODE END PV */

void SystemClock_Config(void);
static void MX_GPIO_Init(void);
static void MX_DMA_Init(void);
static void MX_ADC1_Init(void);
static void MX_I2C2_Init(void);
static void MX_TIM2_Init(void);
static void MX_TIM4_Init(void);
static void MX_USART1_UART_Init(void);
static void MX_TIM3_Init(void);
/* USER CODE BEGIN PFP */
//void mypinSet();
uint8_t myI2CInit();
void myI2CWriteMulti(uint8_t address, uint8_t reg, uint8_t *data, uint16_t count);
void myI2CWrite(uint8_t address, uint8_t reg, uint8_t data);
void decode(uint8_t *payloadBuf, uint8_t lenPx);
void onUSBRx(char *myBuf, int length);
//uint8_t onWiFiTx(char Txdata);
//void onWiFiRx(char *Rxdata, int RxLength);
//void TxCOM(uint8_t *TxBuf, int length);
void display_debug(char txt[],uint8_t X,uint8_t Y);
void MPU6050_Read_Data(void);
uint8_t MPU6050_Init(void);
void IR_PROMEDIO();
void MPU_PROMEDIO();
int8_t Line_detection();
void Pwm_Step();

void ESP01_CH_PD_Set(uint8_t value);
void ESP01_UART_Receive(uint8_t value);
int ESP01_UART_Send(uint8_t value);
void ESP01_ChangeState(_eESP01STATUS statusESP01);

/* USER CODE END PFP */

/* USER CODE BEGIN 0 */

/**
 * @brief Muestra un texto en un display OLED SSD1306 en una posición específica.
 *
 * Esta función borra la pantalla OLED, posiciona el cursor en las coordenadas (x, y)
 * indicadas y muestra el texto deseado utilizando la fuente `Font_7x10`. Finalmente,
 * actualiza la pantalla para reflejar los cambios.
 *
 * @param text Puntero a la cadena de texto que se desea mostrar.
 * @param x Coordenada horizontal (en píxeles) donde se colocará el texto.
 * @param y Coordenada vertical (en píxeles) donde se colocará el texto.
 */
void display_debug(char txt[],uint8_t x,uint8_t y) {
    //SSD1306_Clear(); // Borra la pantalla OLED
    SSD1306_GotoXY(x, y); // Posiciona el cursor en las coordenadas especificadas
    SSD1306_Puts(txt, &Font_7x10, 1); // Muestra el texto en la pantalla
    SSD1306_UpdateScreen(); // Actualiza la pantalla con el nuevo contenido
}
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

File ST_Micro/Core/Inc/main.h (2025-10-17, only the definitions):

#define LED_Pin GPIO_PIN_13
#define LED_GPIO_Port GPIOC
#define ChipEnable_Pin GPIO_PIN_8
#define ChipEnable_GPIO_Port GPIOA

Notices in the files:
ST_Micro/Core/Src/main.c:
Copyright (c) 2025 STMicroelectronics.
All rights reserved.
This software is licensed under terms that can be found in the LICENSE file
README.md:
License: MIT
